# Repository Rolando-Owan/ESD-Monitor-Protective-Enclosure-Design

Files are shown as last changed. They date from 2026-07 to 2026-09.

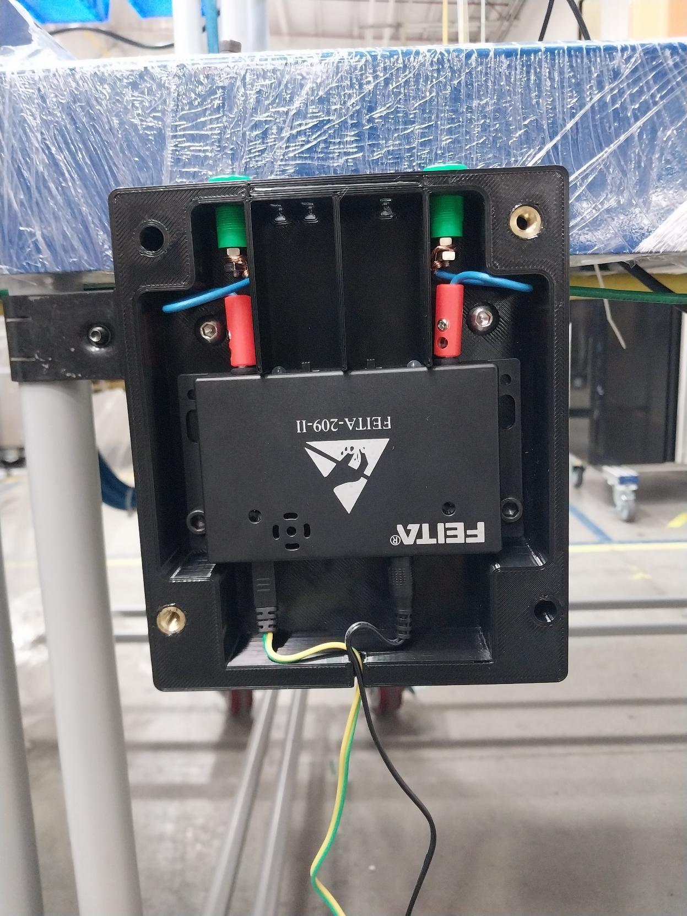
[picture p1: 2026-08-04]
Images/Exposed components.jpg

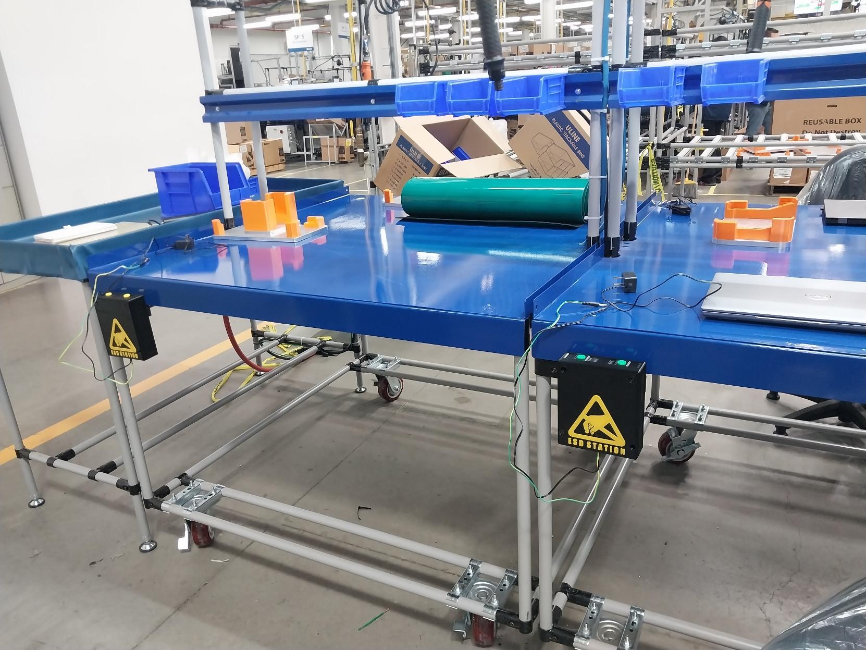
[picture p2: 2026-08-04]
Images/Set-up in production lines.jpg

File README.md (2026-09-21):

# ESD Monitor Protective Enclosure

A custom-designed 3D-printed enclosure developed to protect the FEITA-209-2 ESD Monitor from mechanical damage while improving maintainability through the use of replaceable banana connectors.

655849843-ce06a4b1-6260-492a-a42c-41bbeabe29eb

---

## Project Overview

In a manufacturing environment, the FEITA-209-2 ESD Monitor was frequently damaged due to repeated insertion and removal of workstation and wrist strap banana plugs. Since the original banana ports are integrated into the monitor, mechanical wear often required replacement of the entire unit, increasing maintenance costs and equipment downtime.

To address this issue, a custom protective enclosure was designed and manufactured. The enclosure relocates the electrical connection to external replaceable banana connectors, allowing inexpensive consumable components to absorb mechanical wear while preserving the integrity of the original monitor.

---

## Objectives

- Protect the ESD monitor from mechanical damage.
- Extend the service life of the equipment.
- Reduce maintenance and replacement costs.
- Improve serviceability through replaceable connectors.
- Maintain full functionality and visibility of the monitor indicators.
- Create a solution suitable for additive manufacturing.

---

## Features

- Custom 3D-printed enclosure.
- Replaceable 4 mm banana connectors.
- Transparent front cover for continuous visibility of workstation and wrist strap status LEDs.
- Heat-set threaded inserts for durable assembly.
- Modular design for easy maintenance.
- Two-color printed top cover with integrated ESD warning label.

---

## Design Process

The enclosure was designed in **SolidWorks** following Design for Additive Manufacturing (DfAM) principles.

The assembly consists of:

- Main Case
- Main Case Top
- Transparent Front Cover
- FEITA-209-2 ESD Monitor
- Replaceable Banana Connectors
- Heat-Set Inserts
- Socket Head Screws

Every component was modeled to ensure proper fit, ease of assembly, and reliable long-term operation in a manufacturing environment.

---

## Manufacturing

The enclosure was manufactured using FDM 3D printing.

### Materials

| Component | Material |
|---|---|
| Main Case | Black ESD-Safe PETG |
| Main Case Top | Black ESD-Safe PETG + Yellow PETG |
| Transparent Front Cover | Transparent PP |

Detailed printing parameters can be found in the **3D Printing Guide**.

---

## Repository Structure

```
CAD/
│── SolidWorks parts and assemblies

STL/
│── Printable models

Drawings/
│── Engineering drawings

Documentation/
│── Assembly instructions
│── 3D printing guide

Images/
│── Project renders and photographs
```

---

## Assembly

The enclosure is assembled using standard socket head screws and threaded heat-set inserts to provide a durable and serviceable structure. The replaceable banana connectors are internally wired to the ESD monitor using 22 AWG stranded copper wire, allowing worn connectors to be replaced without affecting the monitor itself. Detailed assembly drawings, the Bill of Materials, and manufacturing documentation are included in the Documentation folder.

---

## Results

The final design successfully protects the original ESD monitor from mechanical damage while transferring connector wear to inexpensive, replaceable banana connectors. This approach reduces maintenance costs, extends the service life of the equipment, and preserves full visibility of the workstation and wrist strap status LEDs. The enclosure also provides a cleaner, more robust appearance suitable for continuous use in a manufacturing environment.



---

## Software Used

The enclosure and all engineering drawings were designed using SolidWorks, while the STL files were prepared for manufacturing with PrusaSlicer. Version control and project documentation are managed through GitHub, ensuring an organized workflow and complete project traceability.

---

## Skills Demonstrated

- Mechanical Design
- CAD Modeling
- Product Improvement
- Design for Additive Manufacturing (DfAM)
- Rapid Prototyping
- FDM 3D Printing
- Engineering Documentation
- Technical Drawings
- Root Cause Analysis
- Problem Solving

---

## License

This project is provided for portfolio and educational purposes.

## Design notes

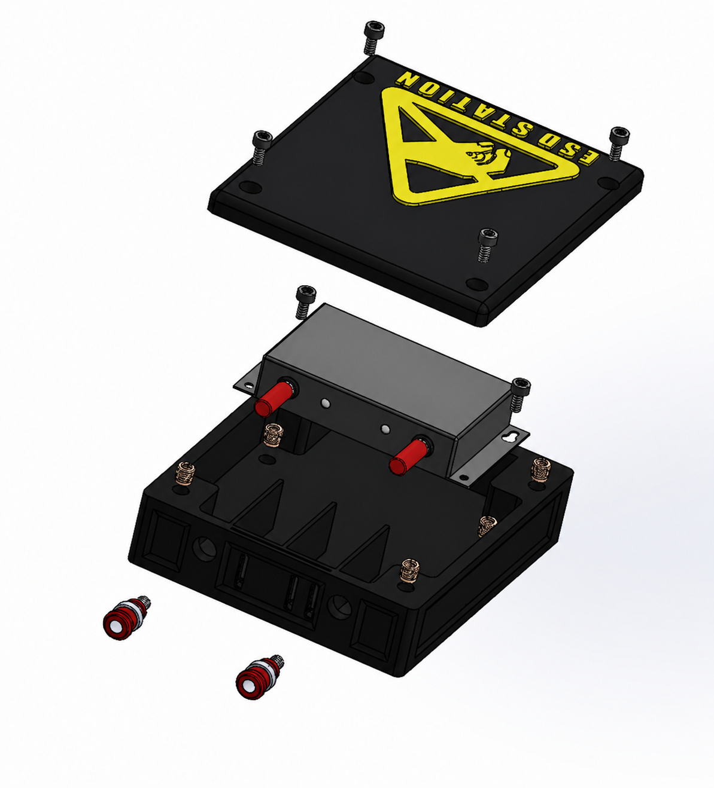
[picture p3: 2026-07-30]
Images/High resolution exploded view.png

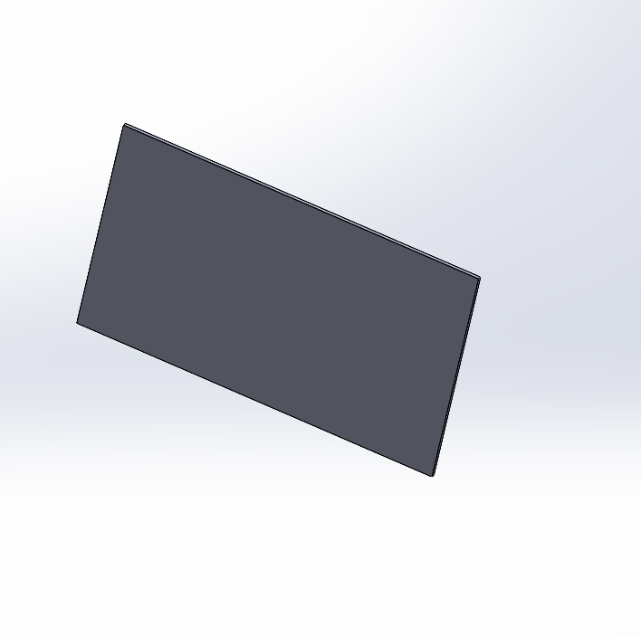
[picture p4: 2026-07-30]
Images/Transparent cover.png

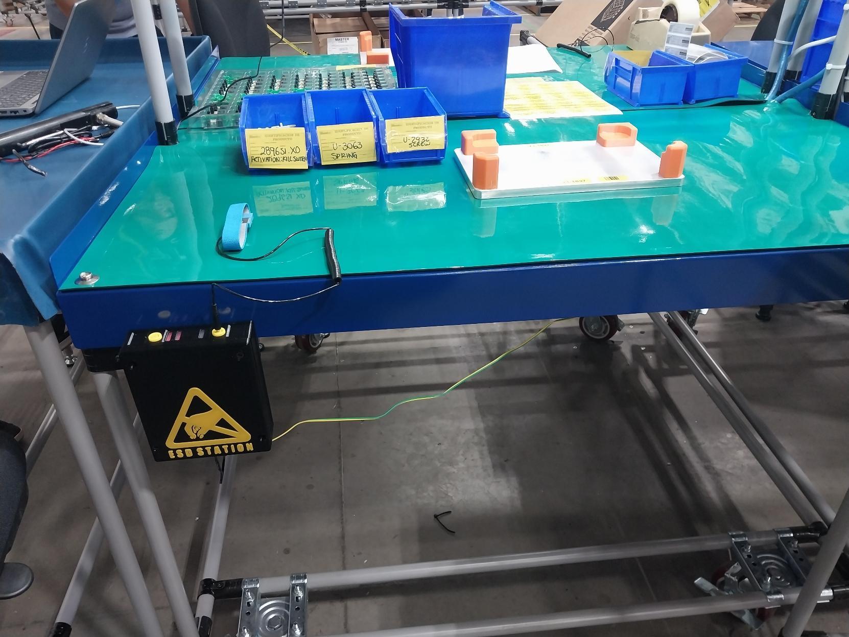
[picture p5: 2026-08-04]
Images/Set-up in work station.jpg

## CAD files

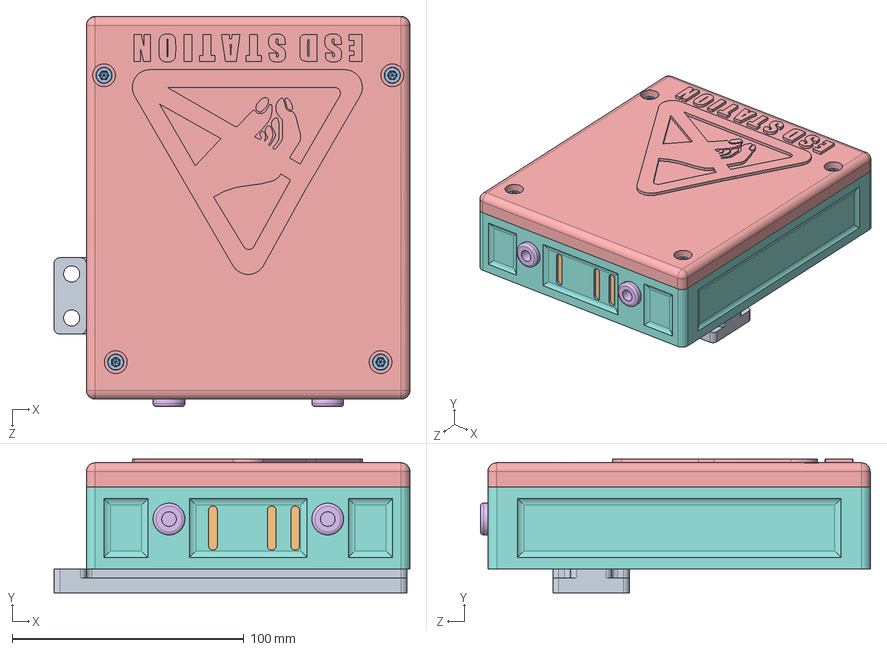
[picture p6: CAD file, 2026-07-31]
CAD/Full case assen.SLDASM
153.7 x 57.7 x 168.4 mm
FEITA-209-2
Main case
Male banana adapter x 2
Female banana adapter x 2
Main case top
ZWMSSLL INSERT x 6
Socket Head Screw 0.25-20 in x 6
Case transparent cover
Station adapter

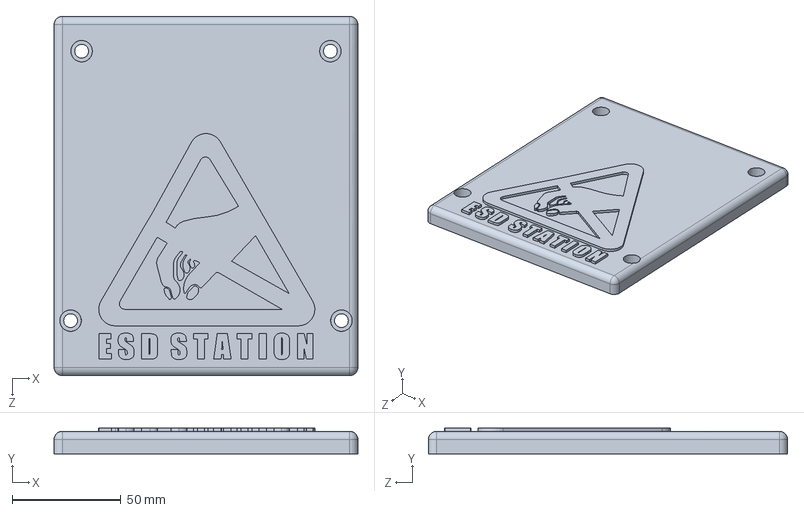
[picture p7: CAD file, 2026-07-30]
CAD/Main case top.SLDPRT
139.7 x 11.9 x 165.1 mm

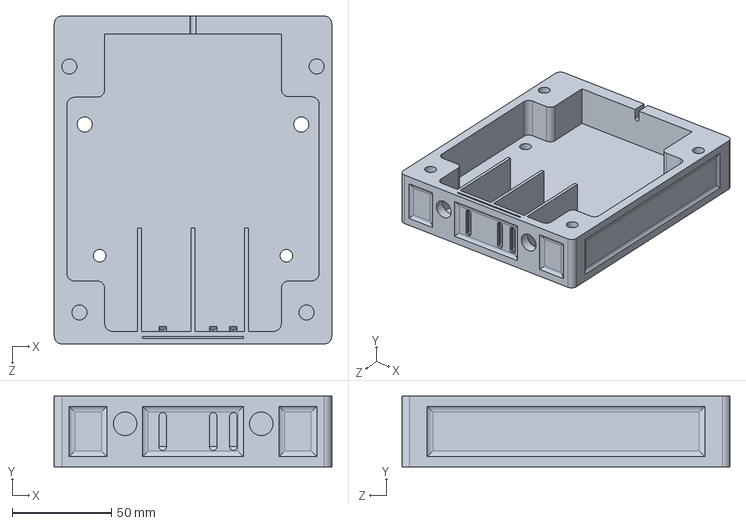
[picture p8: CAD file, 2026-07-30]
CAD/Main case.SLDPRT
139.7 x 35.6 x 165.1 mm

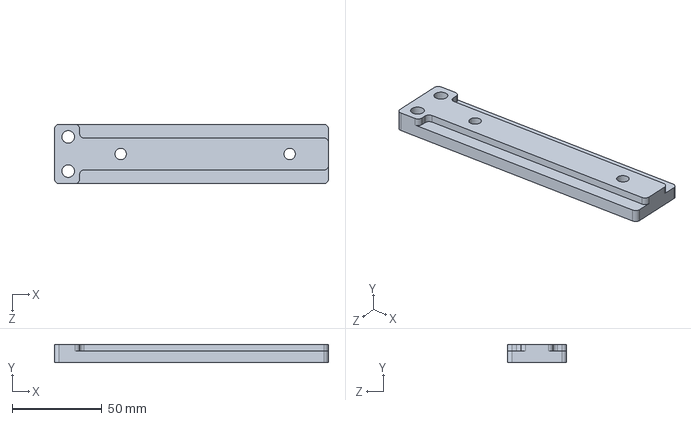
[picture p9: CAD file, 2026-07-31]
CAD/Station adapter.SLDPRT
152.4 x 10.2 x 33.0 mm

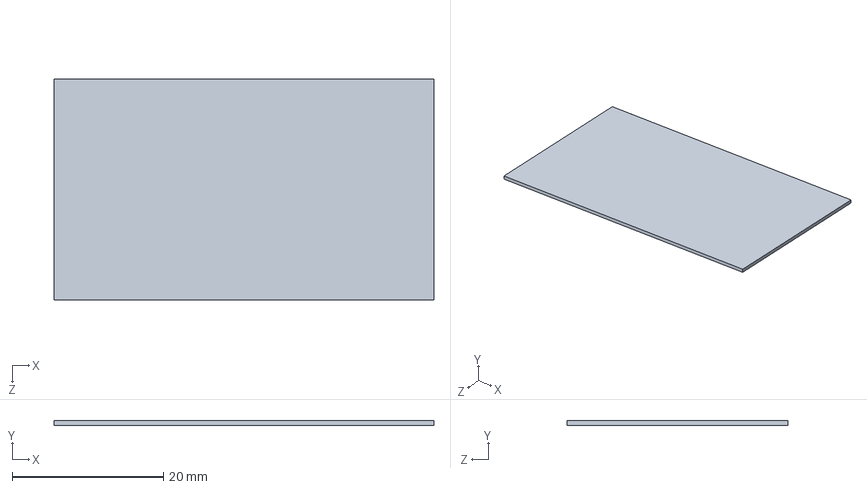
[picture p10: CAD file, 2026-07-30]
CAD/Case transparent cover.SLDPRT
50.3 x 0.6 x 29.2 mm

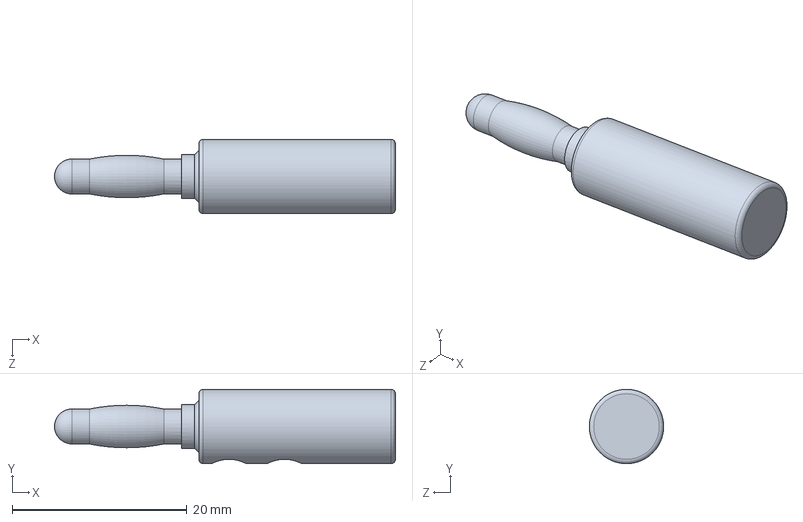
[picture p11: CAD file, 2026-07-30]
CAD/Male banana adapter.SLDPRT
39.0 x 8.50 x 8.50 mm

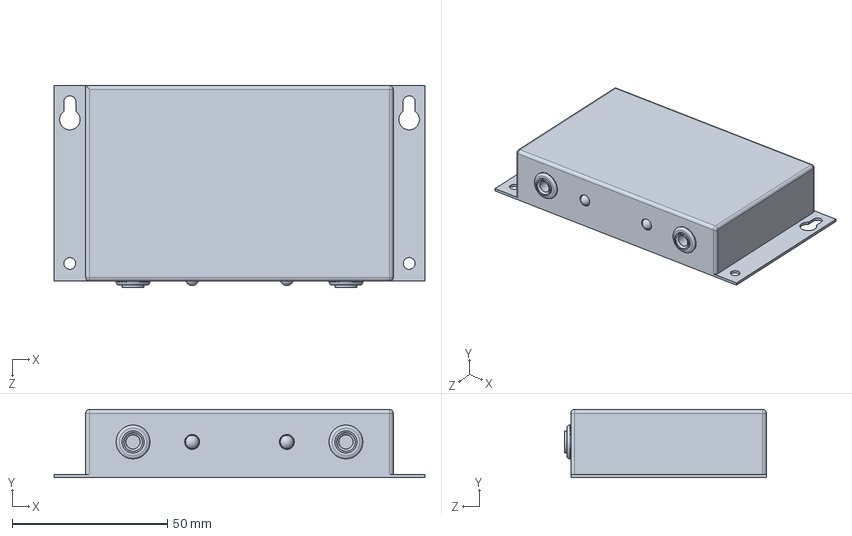
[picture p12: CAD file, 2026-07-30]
CAD/FEITA-209-2.SLDPRT
119.4 x 22.0 x 65.0 mm

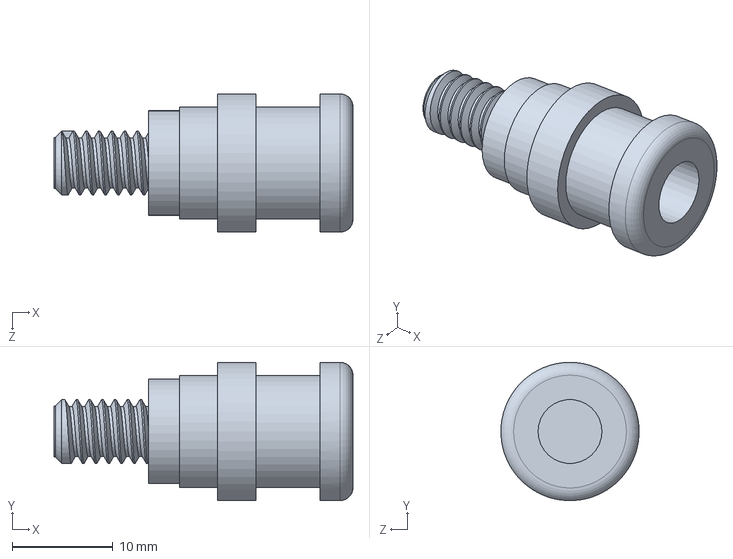
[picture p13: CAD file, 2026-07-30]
CAD/Female banana adapter.SLDPRT
29.7 x 13.7 x 13.7 mm

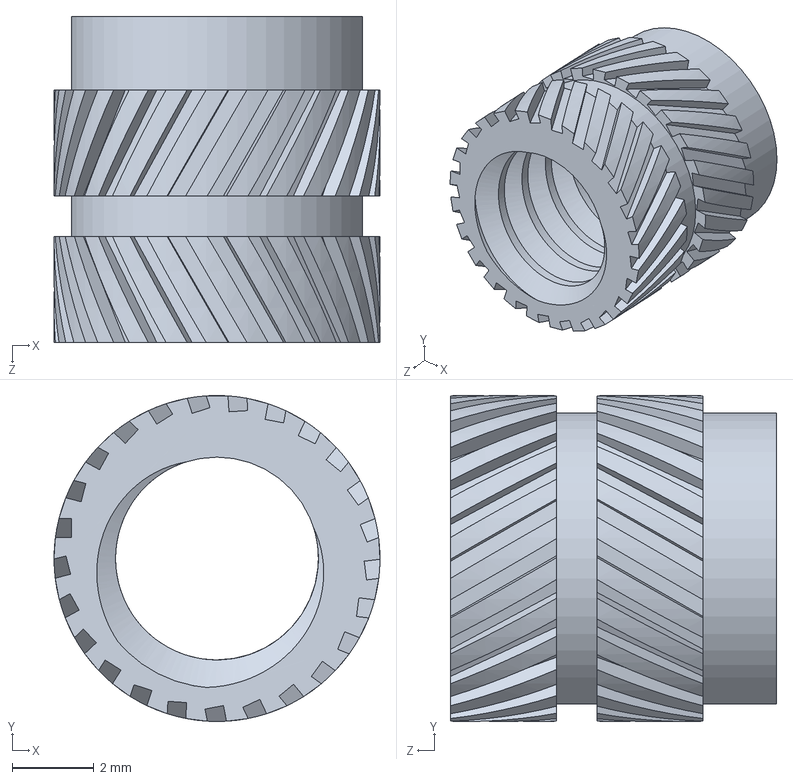
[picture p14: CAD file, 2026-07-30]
CAD/ZWMSSLL INSERT.SLDPRT
8.00 x 8.00 x 8.00 mm

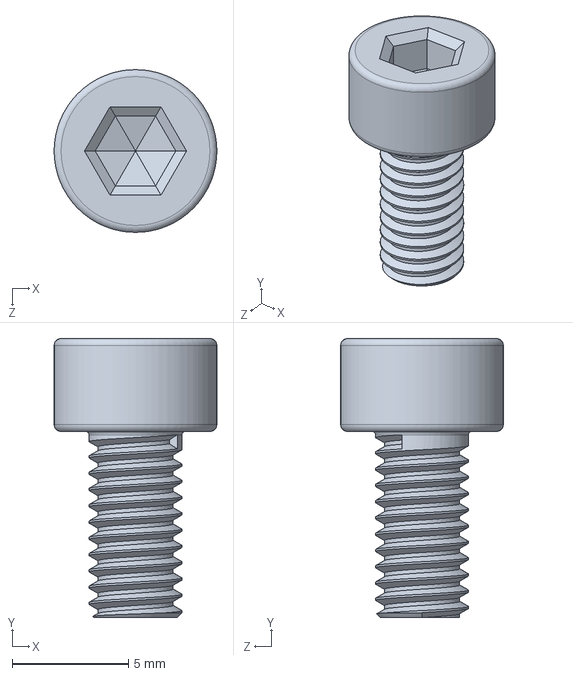
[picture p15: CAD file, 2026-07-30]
CAD/Socket Head Screw 0.25-20 in.SLDPRT
7.00 x 12.0 x 7.00 mm

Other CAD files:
Drawings/Case transparent cover.SLDDRW
Drawings/Main case top.SLDDRW
Drawings/Main case.SLDDRW
STL/Case transparent cover.STL
STL/Main case top.STL
STL/Main case.STL

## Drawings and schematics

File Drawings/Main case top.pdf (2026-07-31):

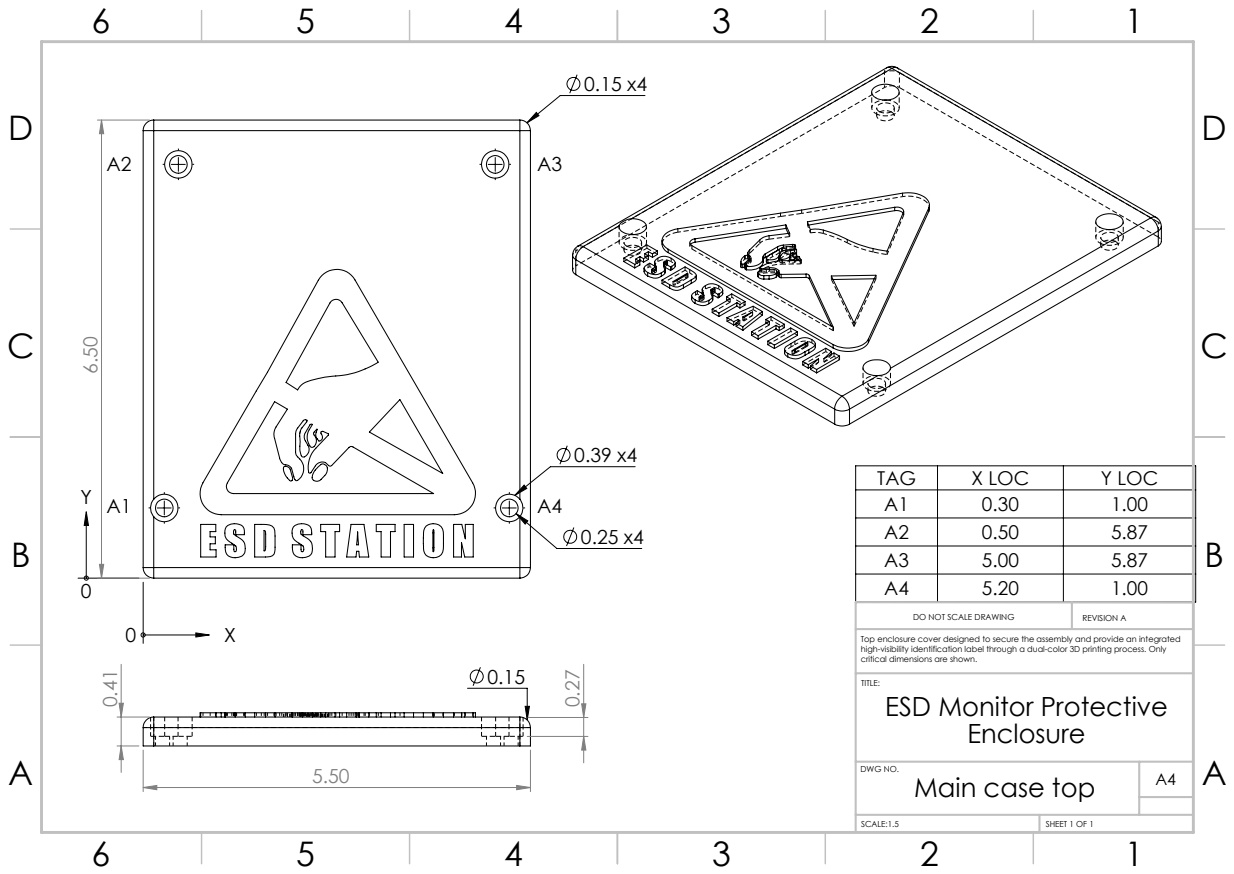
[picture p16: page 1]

TAG | X LOC | Y LOC
A1 | 0.30 | 1.00
A2 | 0.50 | 5.87
A3 | 5.00 | 5.87
A4 | 5.20 | 1.00

DO NOT SCALE DRAWING | REVISION A

Top enclosure cover designed to secure the assembly and provide an integrated
high-visibility identification label through a dual-color 3D printing process. Only
critical dimensions are shown.
ESD Monitor Protective
Enclosure

DWG NO. | A4 Main case top

SCALE:1.5 | SHEET 1 OF 1

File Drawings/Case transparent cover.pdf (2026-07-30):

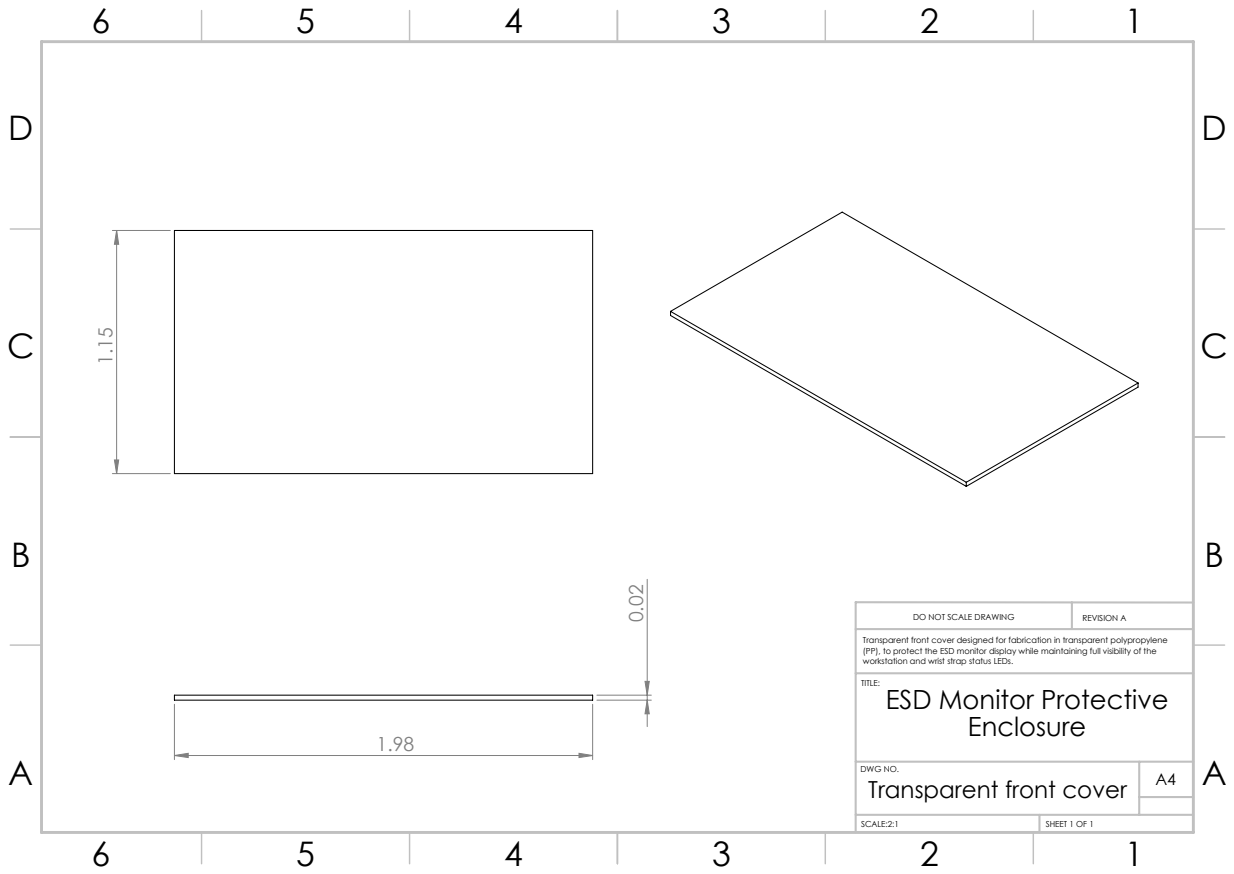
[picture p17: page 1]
DO NOT SCALE DRAWING; REVISION A; SCALE:2:1; SHEET 1 OF 1

Transparent front cover designed for fabrication in transparent polypropylene
(PP), to protect the ESD monitor display while maintaining full visibility of the
workstation and wrist strap status LEDs.
ESD Monitor Protective
Enclosure

DWG NO.
A4 Transparent front cover

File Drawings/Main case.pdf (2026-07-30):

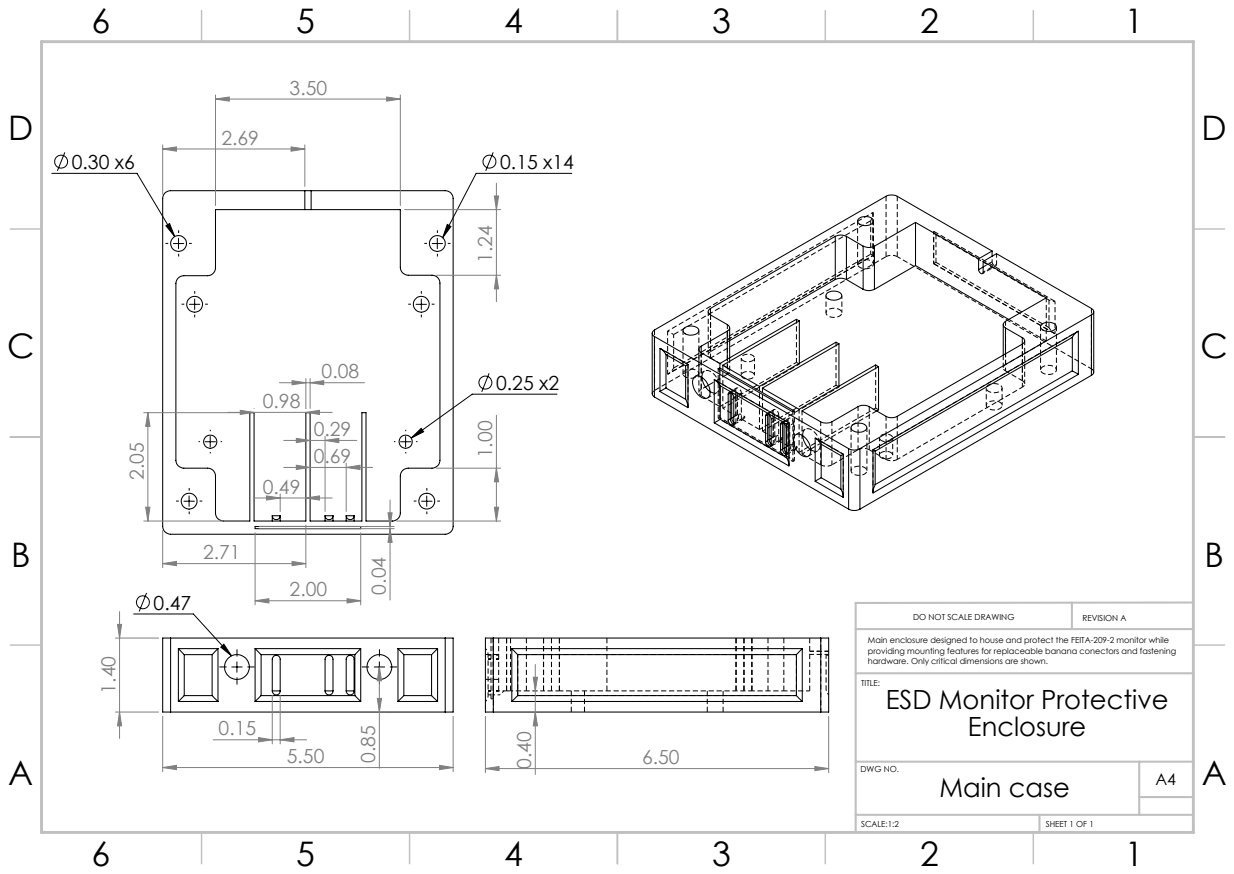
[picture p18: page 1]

DO NOT SCALE DRAWING | REVISION A

Main enclosure designed to house and protect the FEITA-209-2 monitor while
providing mounting features for replaceable banana conectors and fastening
hardware. Only critical dimensions are shown.
ESD Monitor Protective
Enclosure

DWG NO. | A4 Main case

SCALE:1:2 | SHEET 1 OF 1

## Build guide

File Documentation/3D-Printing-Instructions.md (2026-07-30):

# 3D Printing Instructions

The enclosure components are designed for FDM 3D printing. Follow the recommendations below to ensure proper fit, appearance, and functionality. 
The recommended print settings were established using the 3D printers available at Hunter Industries with all models sliced using Prusa Slicer. 
These parameters may require adjustment when using different printers, materials, or slicer configurations. 

## Materials

| Component | Material | Color |
|---|---|---|
| Main Case | ESD-Safe PETG | Black |
| Main Case Top | ESD-Safe PETG / PETG | Black / Yellow  |
| Transparent Front Cover | Transparent PP | Natural (Clear) |

## Main Case

- Printing Technology: FDM
- 3D Printer Model: Prusa MK4S
- Nozzle Diameter: 0.60 mm
- Layer Height: 0.30 mm
- Material: Black ESD-Safe PETG
- Infill: 15%
- Wall Count: 3
- Supports: Disabled
- Build Plate Adhesion: Brim

## Main Case Top

- Printing Technology: FDM
- 3D Printer Model: Prusa XL
- Nozzle Diameter: 0.80 mm
- Layer Height: 0.40 mm
- Extruder 1 Material: Black ESD-Safe PETG
- Extruder 2 Material: Yellow PETG
- Infill: 15%
- Wall Count: 3
- Supports: Disabled
- Build Plate Adhesion: Brim
- Add Height Range Modifier: 0.00 - 10.60 mm (Extruder 1), 10.60 - 12.00 mm (Extruder 2)

## Transparent Front Cover

- Printing Technology: FDM
- 3D Printer Model: Prusa MK4S
- Nozzle Diameter: 0.60 mm
- Layer Height: 0.30 mm
- Material: Transparent PP
- Infill: 15%
- Wall Count: 3
- Supports: Disabled
- Build Plate Adhesion: Disabled

## Post-Processing

- Remove all brim material.
- Inspect each printed component for defects.
- Verify proper fit before final assembly.
- Clean the transparent cover before installation to remove fingerprints and debris.

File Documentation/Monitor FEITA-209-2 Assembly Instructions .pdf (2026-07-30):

MONITOR FEITA-209-2 ASSEMBLY INSTRUCTIONS | REV A

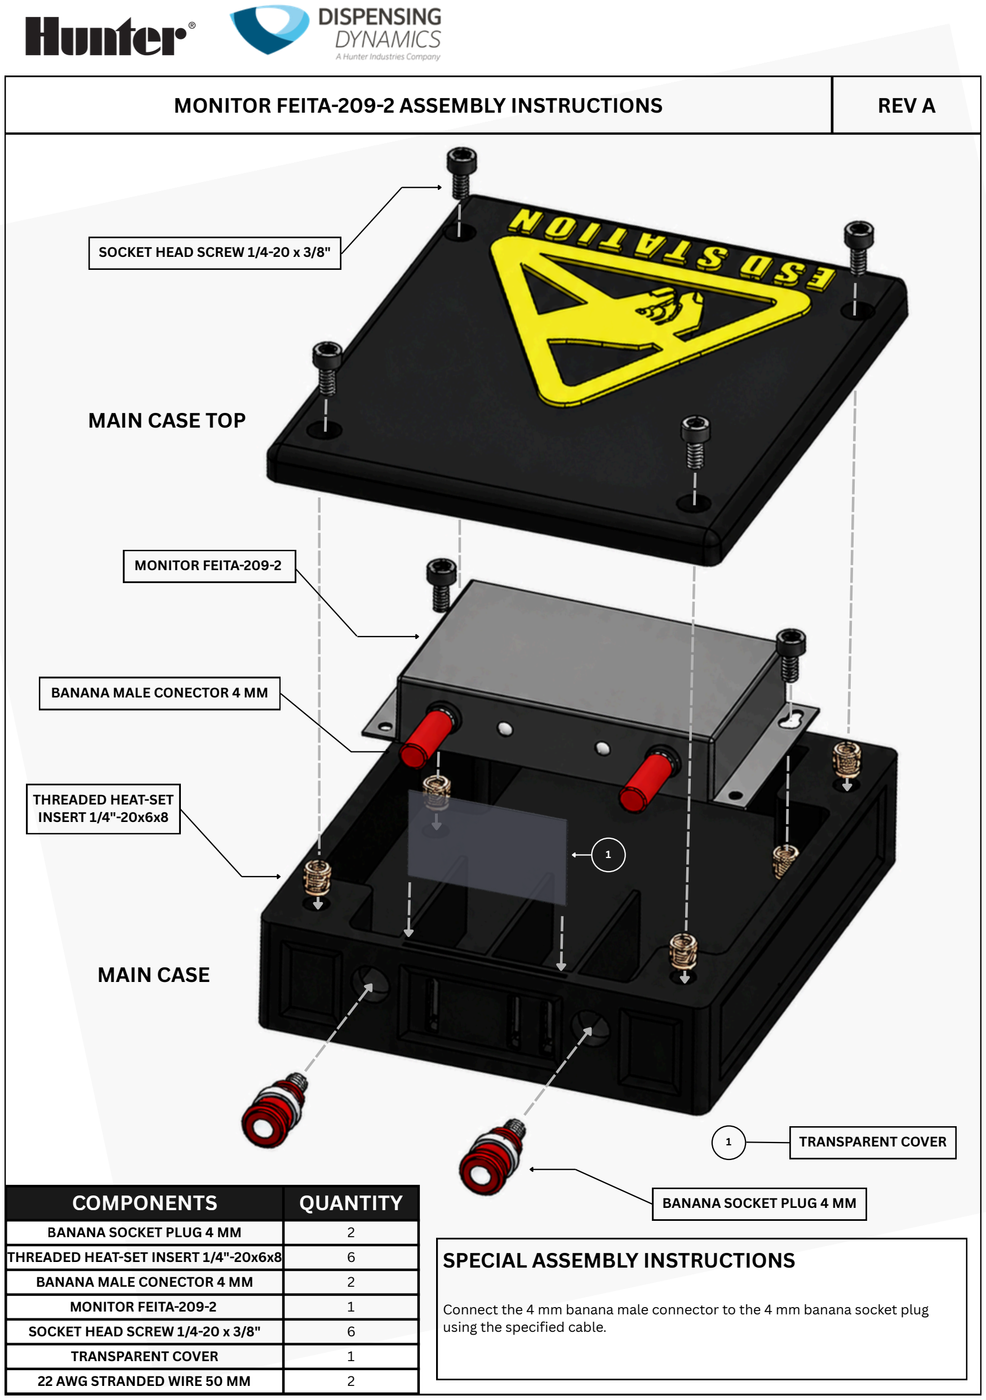
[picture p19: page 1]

BANANA MALE CONECTOR 4 MM

BANANA SOCKET PLUG 4 MM

MONITOR FEITA-209-2

SOCKET HEAD SCREW 1/4-20 x 3/8"

THREADED HEAT-SET
INSERT 1/4"-20x6x8
COMPONENTS | QUANTITY BANANA SOCKET PLUG 4 MM | 2
THREADED HEAT-SET INSERT 1/4"-20x6x8 | 6
BANANA MALE CONECTOR 4 MM | 2
MONITOR FEITA-209-2 | 1
SOCKET HEAD SCREW 1/4-20 x 3/8" | 6
TRANSPARENT COVER | 1
22 AWG STRANDED WIRE 50 MM | 2

TRANSPARENT COVER

1

1

## MAIN CASE TOP

## MAIN CASE

## SPECIAL ASSEMBLY INSTRUCTIONS

Connect the 4 mm banana male connector to the 4 mm banana socket plug using the specified cable.

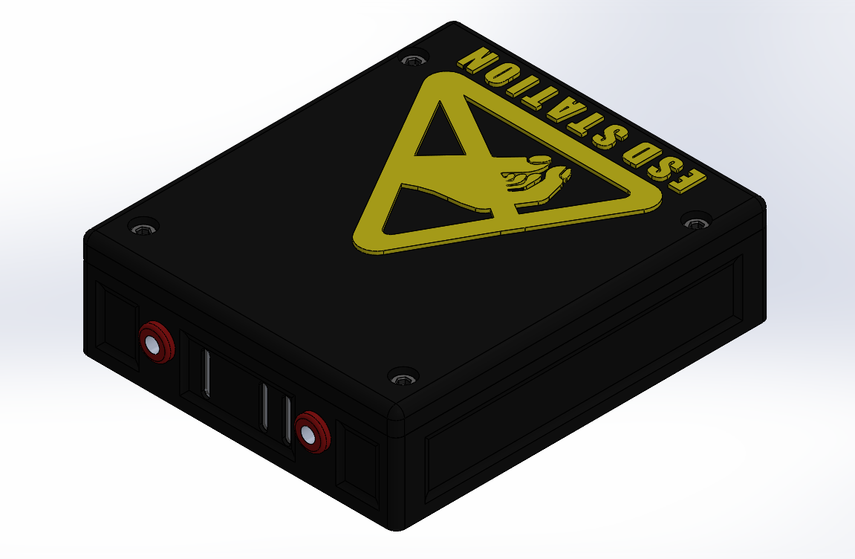
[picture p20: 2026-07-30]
Images/Assembly.png

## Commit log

2026-07-30 Add SolidWorks CAD files
    [Case transparent cover.SLDPRT, FEITA-209-2.SLDPRT, Female banana adapter.SLDPRT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]
2026-07-30 Add STL files
    [Case transparent cover.STL, Main case top.STL, Main case.STL]
2026-07-30 add updated CAD files
    [Case transparent cover.SLDPRT, Full case assen.SLDASM]
2026-07-30 Add printing instructions for STL files
2026-07-30 Updated 3D printing instructions
2026-07-30 Add CAD images
2026-07-30 Add technical drawing files
    [Case transparent cover.SLDDRW, Main case top.SLDDRW, Main case.SLDDRW]
2026-07-31 Updated technical drawings
    [Main case top.SLDDRW]
2026-07-31 Updated CAD files
    [Full case assen.SLDASM, Station adapter.SLDPRT]
